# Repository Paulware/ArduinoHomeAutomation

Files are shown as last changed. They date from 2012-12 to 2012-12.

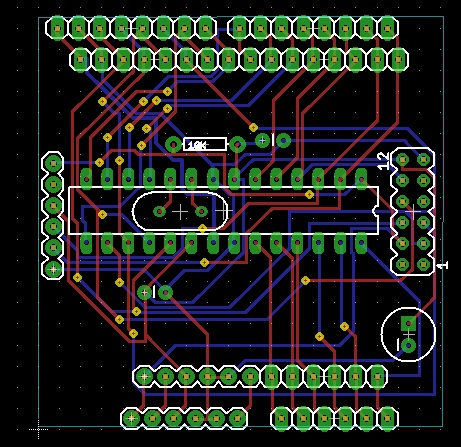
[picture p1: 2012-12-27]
schematics/EtherWeeny2/EtherWeeny2.jpg

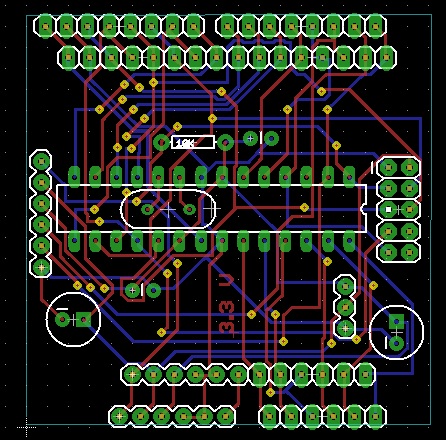
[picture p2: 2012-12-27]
schematics/EtherWeeny/EtherWeeny.jpg

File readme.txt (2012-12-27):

View the HomeAutomation.docx file for detailed information on setup.

Arduino sketches are located in the sketches directory
  The server directory has a the webserver sketch.
  The deviceClient has an example client sketch

Eagle schematics are located for enc28J60 DIY Arduino PCBs.
In the schematics directory
   1) EtherWeeny is a standard pcb for standard 10 pin ENC28J60.  A 3.3 V voltage regulator is added.
   2) EtherWeeny2 is a pcb for the less standard 12 pin ENC28J60.  This device has its own 3.3V regulator built in.

Web-Pages that can be run on an ipad or laptop are located in the webPages directory.
   1) tank.htm is an example that can be used to drive a tank.  A specific matching client sketch is not yet
      available for this tank.htm   
   
Future schematics and sketches will be added for X-10 control.

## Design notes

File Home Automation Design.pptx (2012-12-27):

## Home Automation Design

http://fiverr.com/paulware/help-with-your-arduino-project

## Overview

Ipad/laptop/notebook control

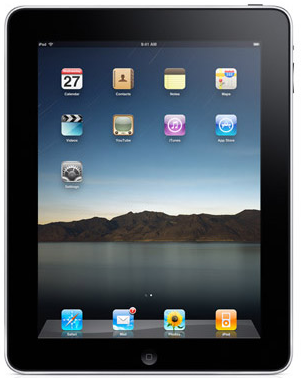
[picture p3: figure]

ENC28J60 web-server connected to wireless router

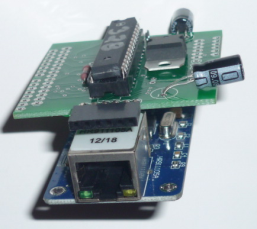
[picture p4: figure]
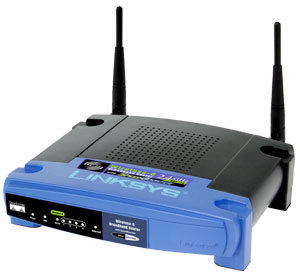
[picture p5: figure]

ENC28J60 web-client connected to TP-LINK 702n router repeater

Mobile Device

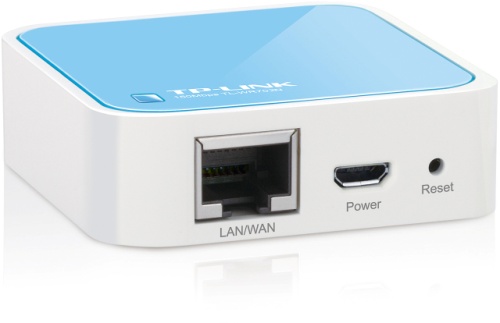
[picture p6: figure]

## Printed Circuit Board

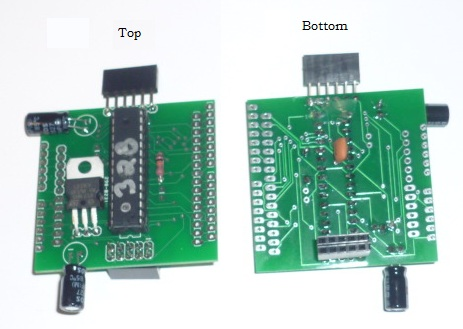
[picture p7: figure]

## CP2102 Usb to Serial Converter

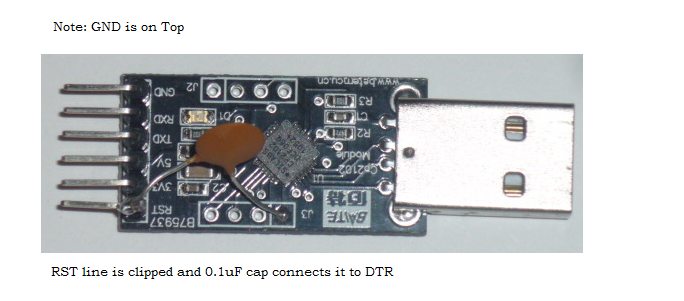
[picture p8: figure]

## Ready for Programming

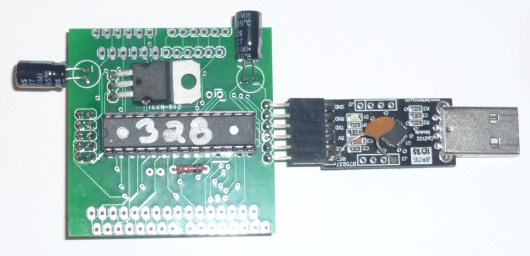
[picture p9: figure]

Select 328 in Arduino IDE Tools, Board

## 5 volt usb power supply

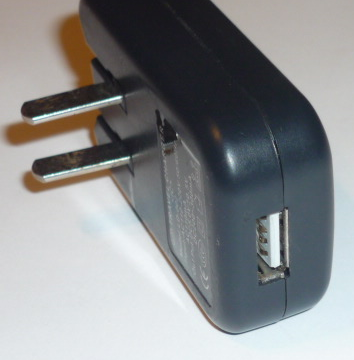
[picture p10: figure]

Available from ebay for $3.00

## Connect to power supply

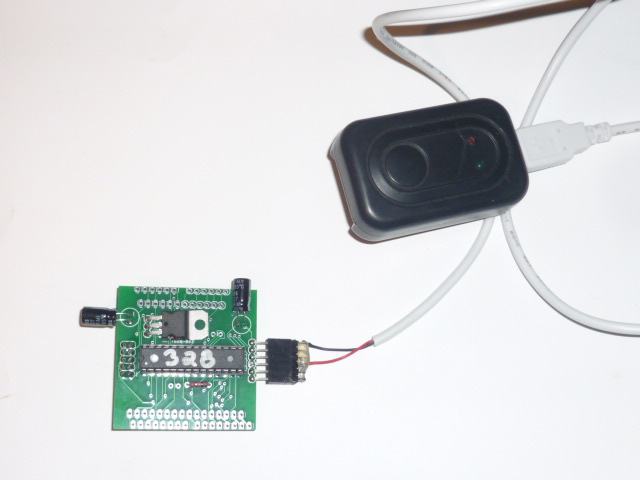
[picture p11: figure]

Note
GND

## ENC28J60

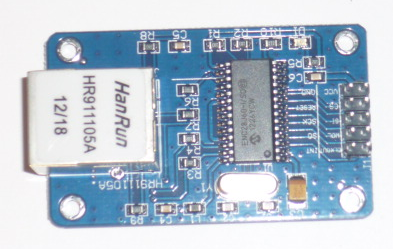
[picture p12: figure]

Available on ebay for less than $5.00 with free shipping

## Connected to ENC28J60

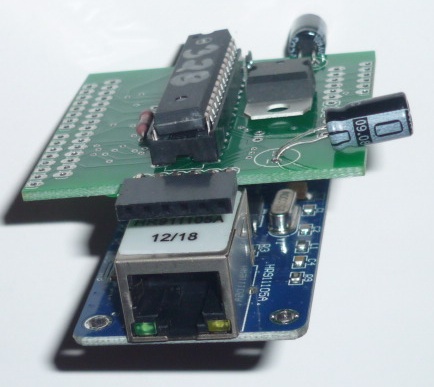
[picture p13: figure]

Web-server and web-clients appear identical

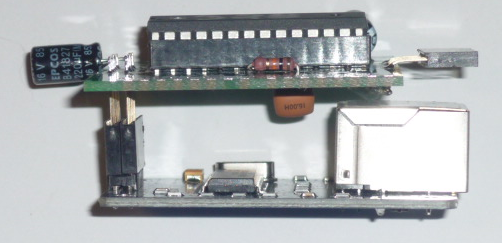
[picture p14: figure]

## Pinout of pcb

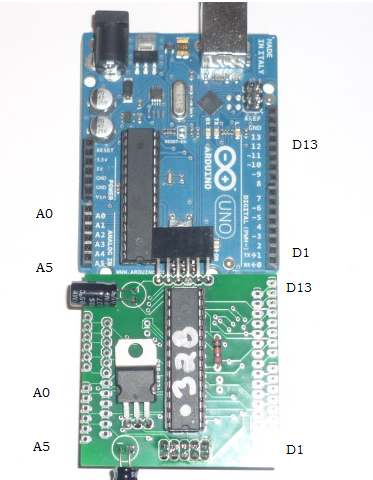
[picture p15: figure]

Same as an Arduino

## Router setup

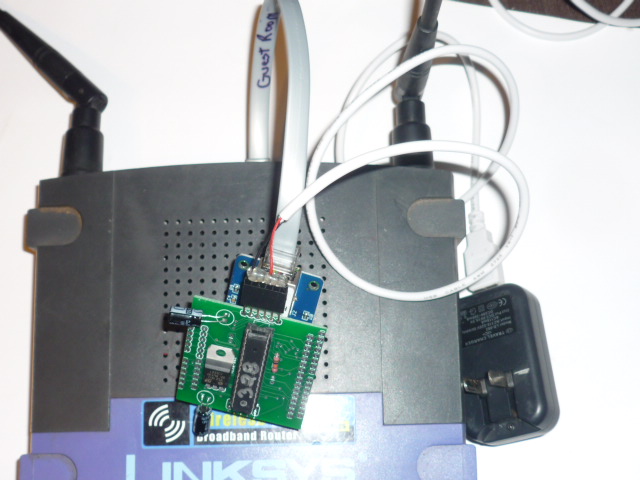
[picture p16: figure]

Web-server is connected here. Sketch should be modified to reflect router address

## X10 Control

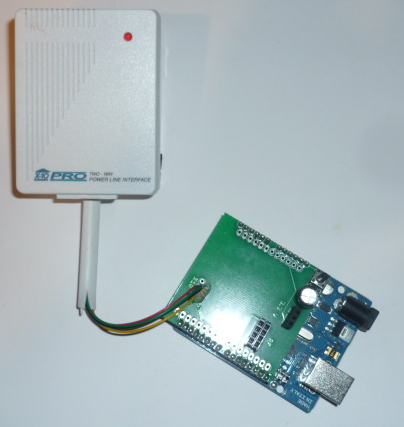
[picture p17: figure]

Arduino can turn X10 devices on or off.

## Mobile Device

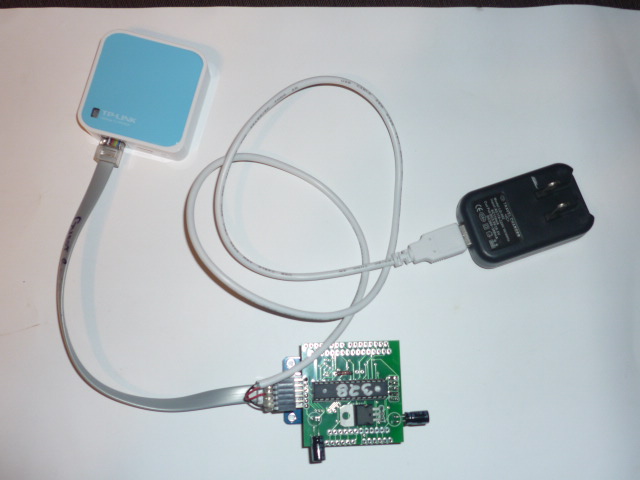
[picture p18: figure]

TP-Link 702n Router Repeater
Give Wifi capability to moble device controlled by Arduino-PCB

## Will move client/server code to github if requested http://fiverr.com/paulware/help-with-your-arduino-project

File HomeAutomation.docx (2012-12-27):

Arduino Home Automation featuring TP-Link 702n and ENC28J60

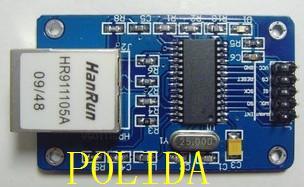
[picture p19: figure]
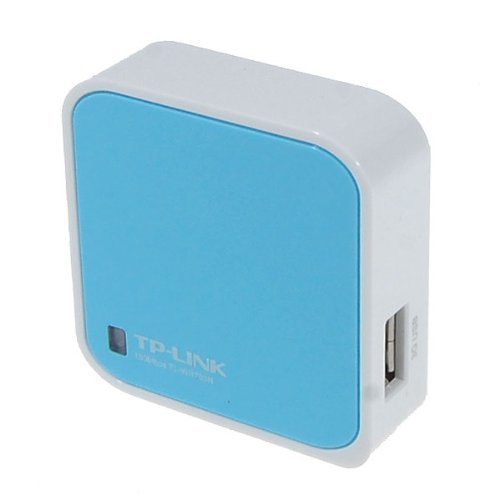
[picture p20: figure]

By Paul Richards and Manuel Tijerino

Overview:

An Ipad can be used to control irrigation systems, lights, house temperature, and even water plants. It can also be used to read temperature sensors, humidity sensors even sump pumps. Inexpensive wireless sensor and control nodes can be created using a TP-Link 702n ($22) and an ENC28J60 ($5.00) and DIY Arduino pcbs ($7.00). X-10 (with a DIY arduino control) can also be used to controlled power to lights.

The system is started with an existing wireless router. TP-Link modules are placed in repeater mode so that ENC28J60 (connected to DIY arduinos) can communicate with the system wirelessly.

Here are the required steps:

1. Place a TP-Link 702n in repeater mode
2. Create a DIY Arduino Web-Server that can be written to ($7.00). Connect it directly to your wireless router
3. Create a DIY Arduino Web-Client and connect it to the TP-Link 702n
4. Command the Web-Client using an Ipad or notebook computer  This project is located on github: https://github.com/Pualware/ArduinoHomeAutomation

Configure a TP-Link in Repeater Mode

1. Set your PC Lan IP4 properties so that it is on the same subnet as the TP-Link 702n (note: the default IP address of a TP-Link 702n is 192.168.0.254)

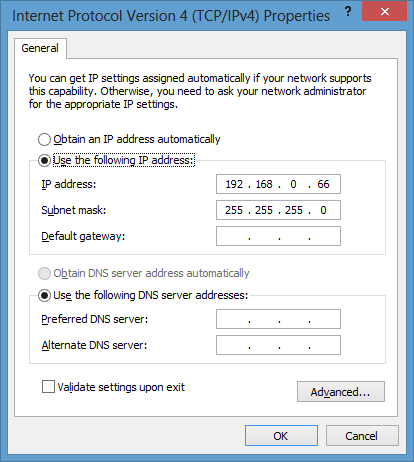
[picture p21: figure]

2. Acces TP-Link 702n located at http://192.168.0.254 from laptop via ethernet cable (note: username is admin, and password is admin). Select Repeater and press the Next button

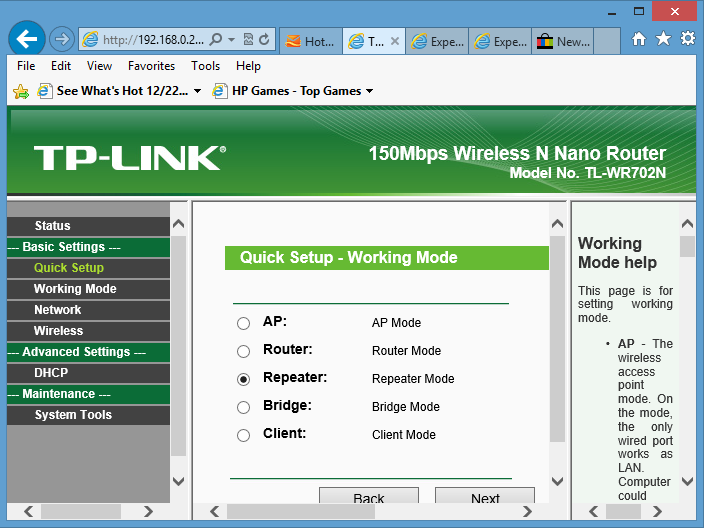
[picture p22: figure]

3. Select Survey and select your network, then select the same Security Options as your network and enter the correct password. Then press Next.

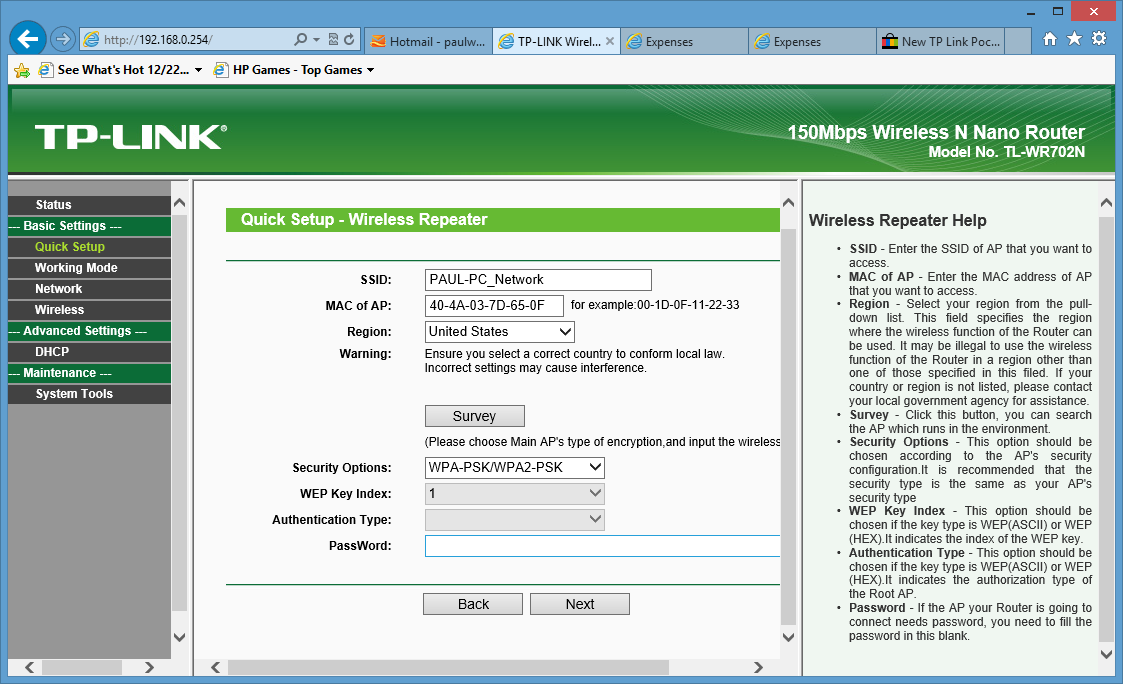
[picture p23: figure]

4. The default setting for DHCP in Repeater mode is disabled. You will need DHCP enabled for your client nodes so enable DHCP in DHCP Settings:

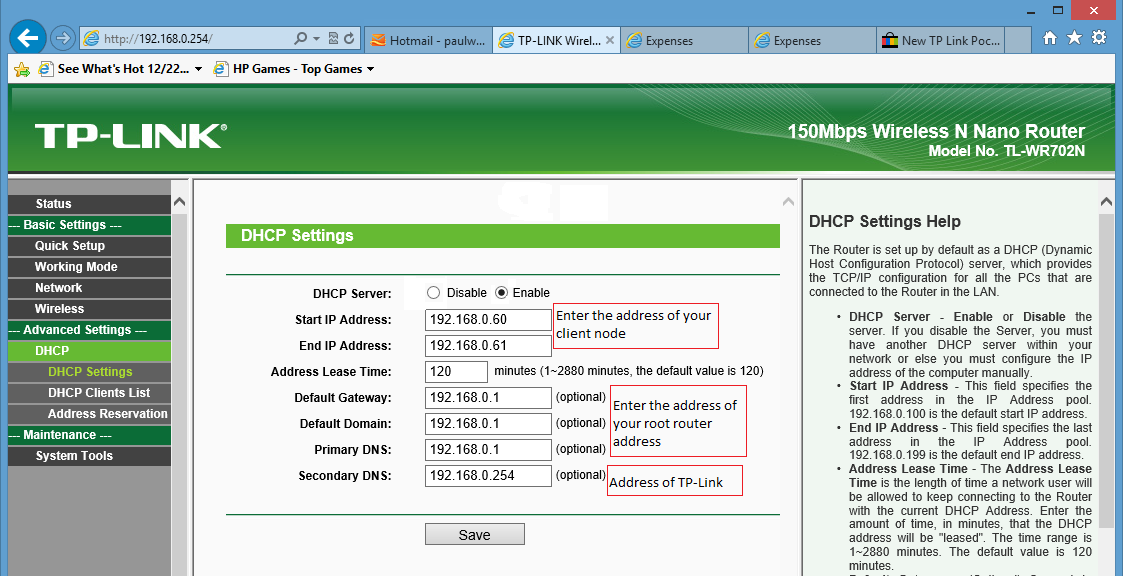
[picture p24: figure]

Your tp-link is now setup. To verify that it works. Turn off your wireless laptop connection and connect an Ethernet cable directly from your laptop to the 702n. You should be able to get to the internet via the tp-link. Change your pc lan properties for TCP/IPV4 to optain IP Address automatically. The Tp-Link will assign the pc the address 192.168.0.60.

You can verify that the pc has the correct ip address by running ipconfig. In windows 8 press the windows key and the “r” this will bring up the Run dialog box. Enter “cmd” and then change directory to c:\windows\system32 from there you run ipconfig and should see:

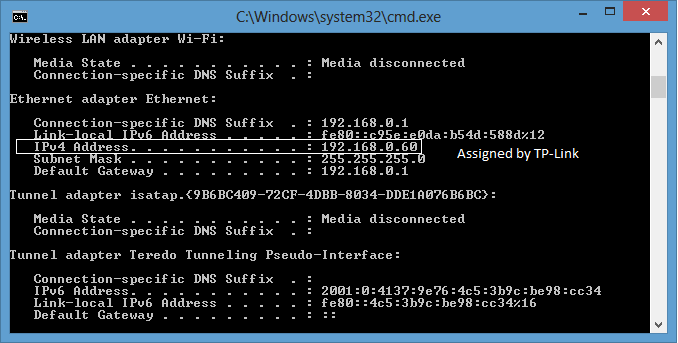
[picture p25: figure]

The system is now ready for the TP-Link 702n to be directly connected to the DIYArduino Client


Connect the 2102 usb to serial adapter to the DIYArduino Client and flash the unit using the Arduino IDE. Use the client sketch found at Github to flash the unit.

From the Arduino IDE, start the serial monitor. Assuming your DIY Arduino webServer is connected and you have already entered the command: http://192.168.0.50/discoverKingTiger1. You should see a display like this in the Serial Monitor:

[webClient]

access Ethernet controller ok

IP: 192.168.0.61

GW: 192.168.0.1

DNS: 192.168.0.1

SRV: 192.168.0.50

0:0:0:0:0:0:100:0:0:100:0:0:0:0:0:0:0:0:0:0

This means that the client has been assigned the address of 192.168.0.61 by the 702n. The gateway is established to the root modem/router. The DNS name server is established to the root modem/router and the DIY web-server located at 192.168.0.50 is visible to the client device. Further, all the port values were read from the web-server for this device named “KingTiger1”

Commands recognized by the DIY Arduino Web-Server are:

1. discover This command lets the web server know that a device exists on the network. It must be followed by a unique device name for example: discoverKingTiger1 For example this lets the web server know that a device by the name of KingTiger1 exists.
2. show This command lists all the devices currently connected. Here is an example output:

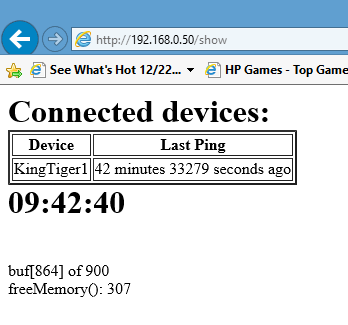
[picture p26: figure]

3. write This command is used to write to ports on the specified device. For example: writeKingTiger1:19:1:5:100:3:200 writes the value 1 to port 19, the value 100 to port 5 and the value 200 to port 3
4. read This command is used to read all the ports on the specified device. For example: readKingTiger1 Tells the web-server to echo the value for all ports on the device KingTiger1.

Sketches for the web server and web-client, as well as the schematics to build the DIY Arduino components will be located on Github:

https://github.com/Pualware/ArduinoHomeAutomation

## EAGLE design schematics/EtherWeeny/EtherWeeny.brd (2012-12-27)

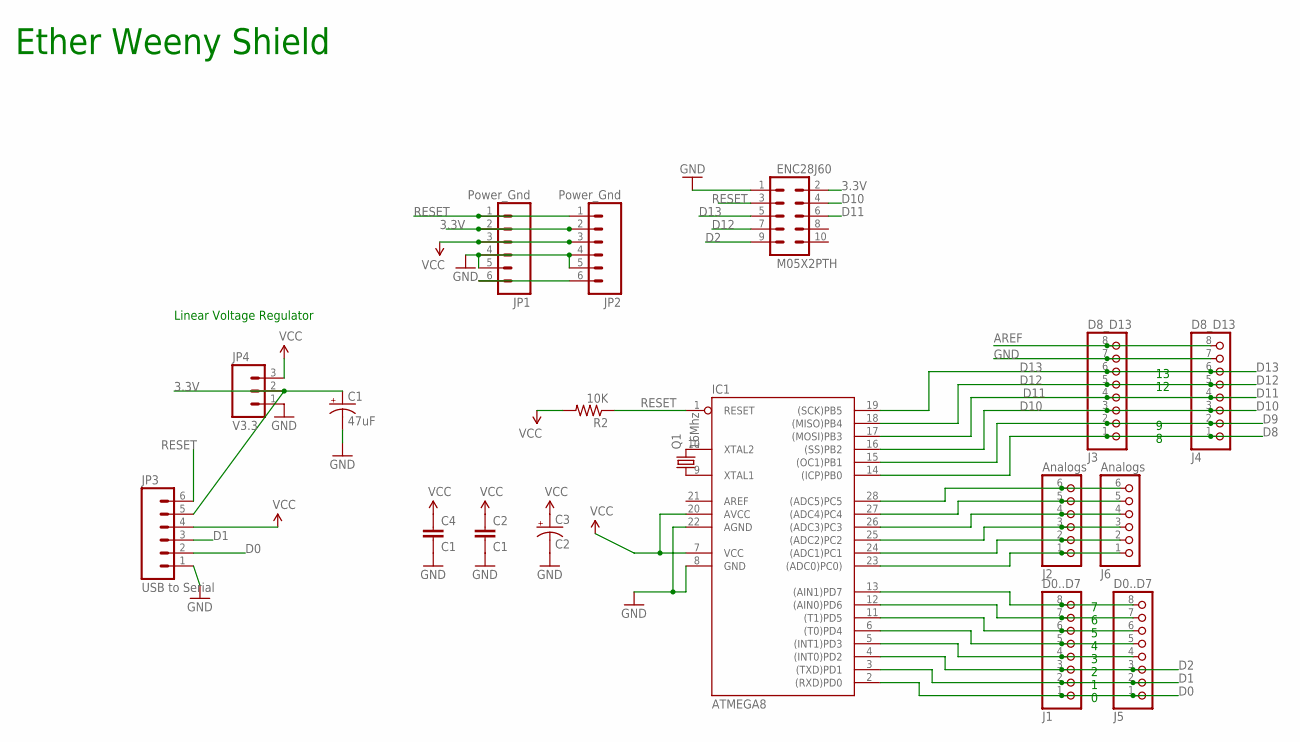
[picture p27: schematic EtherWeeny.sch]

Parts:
C1: 47uF; CPOL-RADIAL-100UF-25V
C2, C4: C1; CAP-PTH-SMALL
C3: C2; CPOL-RADIAL-100UF-25V
ENC28J60: M05X2PTH; AVR_ICSP
IC1: ATMEGA8; DIL28-3
J1, J5: D0..D7; 1X08
J2, J6: Analogs; 1X06
J3, J4: D8_D13; 1X08
JP1, JP2: Power_Gnd; 1X06
JP3: USB to Serial; 1X06
JP4: V3.3; 1X03
Q1: 16Mhz; HC49US
R2: 10K; AXIAL-0.3

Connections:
3.3V: C1.1 (+), ENC28J60.2, JP1.2, JP2.2, JP3.5, JP4.2
AREF: IC1.21 (AREF), J3.8, J4.8
D0: IC1.2 ((RXD)PD0), J1.1, J5.1, JP3.2
D1: IC1.3 ((TXD)PD1), J1.2, J5.2, JP3.3
D2: ENC28J60.9, IC1.4 ((INT0)PD2), J1.3, J5.3
D8: IC1.14 ((ICP)PB0), J3.1, J4.1
D9: IC1.15 ((OC1)PB1), J3.2, J4.2
D10: ENC28J60.4, IC1.16 ((SS)PB2), J3.3, J4.3
D11: ENC28J60.6, IC1.17 ((MOSI)PB3), J3.4, J4.4
D12: ENC28J60.7, IC1.18 ((MISO)PB4), J3.5, J4.5
D13: ENC28J60.5, IC1.19 ((SCK)PB5), J3.6, J4.6
GND: C1.2 (-), C2.2, C3.2 (-), C4.2, ENC28J60.1, IC1.8 (GND), IC1.22 (AGND), J3.7, J4.7, JP1.4, JP1.5, JP2.4, JP2.5, JP3.1, JP4.1
unnamed: IC1.10 (XTAL2), Q1.2
unnamed: IC1.9 (XTAL1), Q1.1
unnamed: JP1.6, JP2.6
unnamed: IC1.5 ((INT1)PD3), J1.4, J5.4
unnamed: IC1.6 ((T0)PD4), J1.5, J5.5
unnamed: IC1.11 ((T1)PD5), J1.6, J5.6
unnamed: IC1.12 ((AIN0)PD6), J1.7, J5.7
unnamed: IC1.13 ((AIN1)PD7), J1.8, J5.8
unnamed: IC1.23 ((ADC0)PC0)), J2.1, J6.1
unnamed: IC1.24 ((ADC1)PC1), J2.2, J6.2
unnamed: IC1.25 ((ADC2)PC2), J2.3, J6.3
unnamed: IC1.26 ((ADC3)PC3), J2.4, J6.4
unnamed: IC1.27 ((ADC4)PC4), J2.5, J6.5
unnamed: IC1.28 ((ADC5)PC5), J2.6, J6.6
RESET: ENC28J60.3, IC1.1 (RESET), JP1.1, JP2.1, JP3.6, R2.P$1 (1)
VCC: C2.1, C3.1 (+), C4.1, IC1.7 (VCC), IC1.20 (AVCC), JP1.3, JP2.3, JP3.4, JP4.3, R2.P$2 (2)

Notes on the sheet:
Ether Weeny Shield
Linear Voltage Regulator

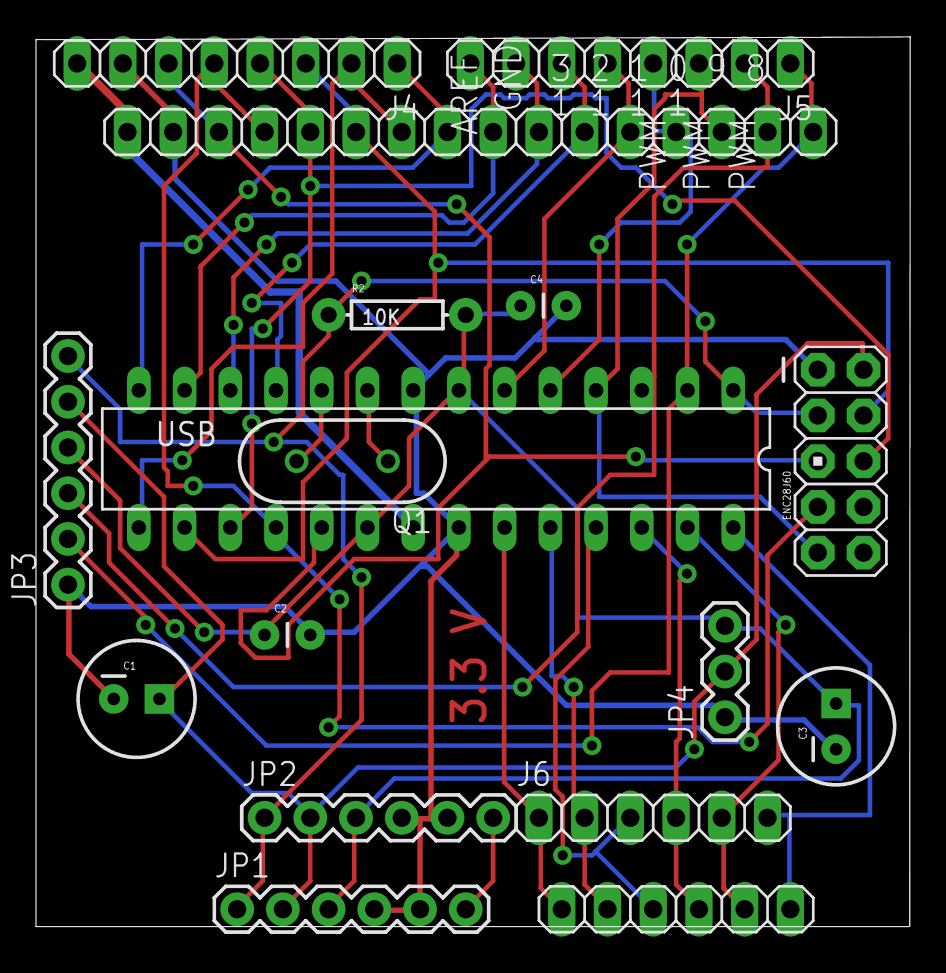
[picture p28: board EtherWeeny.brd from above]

Board: 2 copper layers, 48.6 x 49.4 mm, 18 parts (0 on the bottom side), 28 nets.

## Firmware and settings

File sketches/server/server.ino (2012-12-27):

#include <EtherCard.h>
#include <MemoryFree.h>
#include <EEPROM.h>
#include "ProgmemStrings.h"
#include "EEPROMStructs.h"
#define SERVERIP "192.168.0.50"

static int const MAXBUFFER = 900;

// ethernet interface mac address, must be unique on the LAN
static byte mymac[] = { 
  0x74,0x69,0x69,0x2D,0x30,0x31 };
static byte myip[4];
byte Ethernet::buffer[MAXBUFFER];
BufferFiller bfill;
int numDevices = 0;
ProgmemStrings progStrings(6);
EEPROMStructs structures = EEPROMStructs();

struct DeviceType
{
  unsigned long lastPing;  // last millis() that device sent a ping
  char * name;             // Unique text name of device
};
DeviceType devices[25];

void SetupByteArray (byte * myip )
{
  int len = strlen (SERVERIP);
  int count = 0;
  char serverIp[] = SERVERIP;
  char addr[4];
  int index = 0;

  for (int i=0; i<len; i++)
  {
    if (serverIp[i] == '.')
    {
      addr[count] = 0;
      myip[index++] = (byte) atoi (addr);
      count = 0;
    }  
    else
      addr[count++] = serverIp[i];      
  }

  addr[count] = 0;
  myip[index++] = (byte) atoi (addr);

  ProgmemStrings::printPSTR ( PSTR ( "myip:" ));
  for (int i=0; i<4; i++)
  {
    if (i==0)
      Serial.print ( "{");
    else  
      Serial.print ( ",");
    Serial.print ( myip [i]);    
  }
  Serial.println ("}");     
}

void setup () {
  int which;
  Serial.begin (115200);
  ProgmemStrings::printPSTR ( PSTR ( "rbbb_server_progstrings" ) ); 
  SetupByteArray (myip);
  if (ether.begin(sizeof Ethernet::buffer, mymac) == 0)
    ProgmemStrings::printPSTR ( PSTR ( "Failed to access Ethernet controller"));
  ether.staticSetup(myip);
  
  progStrings.addString ( PSTR ( "discover" ));
  progStrings.addString ( PSTR ( "show" ));
  progStrings.addString ( PSTR ( "page" ));
  progStrings.addString ( PSTR ( "ping" ));
  progStrings.addString ( PSTR ( "write" ));
  progStrings.addString ( PSTR ( "read" ));
  progStrings.showAll();
  ProgmemStrings::printPSTR ( PSTR ( "Free Memory: " ) );
  Serial.println ( freeMemory() );  
}

// str1 is the actual string
bool strEqual ( char * str1, char * str2 )
{
  bool match = true;
  int len = strlen ( str1 );

  if (strlen(str2) < len) 
    match = false;
  else 
    for (int i=0; i<len; i++)
    {
      if (str1[i] != str2[i])
      {
        match = false;
        break;
      }
    }

  return match;
}

int findDevice (char * name)
{
  int found = -1;
  for (int i=0; i<numDevices; i++)
  {
    if (strEqual (devices[i].name, name) )
    {
      found = i;
      break;
    }  
  }  
  return found;
}

char * findParameterStart ()
{
  char ch;
  int index = 0;
  int ind = 0;
  int state = 0;
  byte * startParam;

  while (state != 2)
  {
    ch = ether.buffer[index++];
    if (ch == ' ') 
      state = 1;
    else if ((state == 1) && (ch == '/'))
      state = 2;
    else 
      state = 0;
  }  
  startParam = &ether.buffer[index];
  return (char *)startParam;
}


void findCommand ( char * &line, int & cmd )
{
  int len;
  cmd = progStrings.findString ( line );
  if (cmd > -1)
  {
    len = progStrings.stringLen (cmd );
    line = line + len;
  }
}

char * copyParam ( char * parameter )
{
  int len = 0;
  int offset = 0;
  char ch;
  char * param;
  int state = 0;
  // find out how long is the parameter 
  while (true)
  {
    ch = parameter[len];
    if (ch == ' ') 
      break;
    else 
    {
      Serial.print ( ch ); 
      Serial.print ( " = " );
      Serial.println ( (int) ch );
    }  
    switch (state)
    {
      case 0:
        if (ch == '%')
          state = 1;
      break;
      case 1:
        if (ch == '2')
          state = 2;
        else
          state = 0;
      break;
      case 2:
        if (ch == '0')
          offset -= 2;          
        state = 0;
      break;
    } 
    len++;
  }
  param = (char *) calloc (len+1+offset,1); // allocate the string
  len = 0;
  offset = 0;
  // Copy the parameter
  while (true)
  {
    ch = parameter [len];
    if (ch == ' ')
      break;
    if ((parameter[len] == '%') && (parameter[len+1]=='2') && (parameter[len+2]=='0'))
    {
      ch= ' ';
      len = len + 2;
      offset = offset - 2;
    }  
    param[len+offset] = ch;
    len++;
  }
  ProgmemStrings::printPSTR ( PSTR ( "param: " ));
  Serial.print ( param );
  Serial.println ( "." );
  
  return param;  
}

void loop () {
  word len = ether.packetReceive();
  char * parameter;
  word pos = ether.packetLoop(len);
  char ch;
  bool debugIt = false;
  int pageNumber = -1;
  int command; 
  char * paramCopy;

  if (pos)  // check if valid tcp data is received
  {
    parameter = findParameterStart ();
    findCommand (parameter, command);
    paramCopy = copyParam ( parameter );
    ProgmemStrings::printPSTR ( PSTR ( "paramCopy len:" ));
    Serial.print ( strlen ( paramCopy ) );
    Serial.print ( ":" );
    Serial.println ( paramCopy );
    ProgmemStrings::printPSTR ( PSTR ( "paramCopy: " )); 
    Serial.println ( (int) paramCopy );
    
    ether.httpServerReply(serverPage (command, paramCopy)); // send web page data
    delete (paramCopy);
  }
}

// Do not consume the terminating 0
boolean readDecimal (char * &charPointer, int &total)
{
  char ch;
  boolean ok = false;
  total = 0;
  
  while (true)
  {
    ch = *charPointer;
    // Exit if number if not a decimal
    if ((ch < '0') || (ch > '9'))
      break;
    else
    {
      ok = true;
      charPointer++;
      total *= 10;
      total += ch - '0';
    }    
  }    
  return ok;
}

void handleShow ()
{
  long t = millis() / 1000;
  word h = t / 3600;
  byte m = (t / 60) % 60;
  byte s = t % 60;
  float secondsAgo;
  
  bfill.emit_p(PSTR(
    "HTTP/1.0 200 OK\r\n"
    "Content-Type: text/html\r\n"
    "Pragma: no-cache\r\n"
    "\r\n"
    "<title>Show Devices</title>" 
    "<h1>Connected devices:<br>"
    "<table border=\"2px solid\">"
    "<tr><th>Device</th><th>Last Ping</th></tr>"));

  for (int i=0; i<numDevices; i++)
  {
    Serial.print ( i );
    Serial.print ( "):" );
    Serial.println ( devices[i].name );
    secondsAgo = millis() - devices[i].lastPing;
    secondsAgo /= 1000.0; 
    m = secondsAgo / 60.0;
    if (m > 0) 
      bfill.emit_p (PSTR ( "<tr><td>$S</td><td>$D minutes $D seconds ago</td></tr>"),devices[i].name, m, (int) secondsAgo);
    else  
      bfill.emit_p (PSTR ( "<tr><td>$S</td><td>$D seconds ago</td></tr>"),devices[i].name, (int) secondsAgo);
  }  
  bfill.emit_p (PSTR (
    "</table>"
    " $D$D:$D$D:$D$D</h1><br>buf[$D] of $D<br>"),
    h/10, h%10, m/10, m%10, s/10, s%10, (int) bfill.ptr, MAXBUFFER);
    
  bfill.emit_p (PSTR ( " freeMemory(): $D<br>"), freeMemory());
}

void handleWrite (char * parameter)
{
  int len;
  int device;
  int port;
  int value;

  device = findDevice (parameter); 
  len = strlen (devices[device].name);    
  if (device > -1) 
  {
    parameter += len;
      
    while (readDecimal (++parameter, port ) && readDecimal (++parameter, value))
      structures.updateValue ( device, port, value );
      
    bfill.emit_p(PSTR(
      "HTTP/1.0 200 OK\r\n"
      "Content-Type: text/html\r\n"
      "Pragma: no-cache\r\n"
      "\r\n"
      "<title>ping RBBB server page </title>"
      "<h1>write detected $S device found<br>"), parameter);
  }
  else
  {
    bfill.emit_p(PSTR(
      "HTTP/1.0 200 OK\r\n"
      "Content-Type: text/html\r\n"
      "Pragma: no-cache\r\n"
      "\r\n"
      "<title>ping RBBB server page </title>"
      "<h1>$S<br>"), "Write detected, device not found");
  }
}

void handleRead ( char * parameter )
{
  int len;
  int device;
  int port;
  int value;
  
  device = findDevice (parameter); 
  if (device > -1) 
  {
    len = strlen (devices[device].name);   
    parameter += len;
    ProgmemStrings::printPSTR ( PSTR ( "parameter in read: " ));
    Serial.println ( parameter );
    value = -1; 
    if (readDecimal (++parameter, port ))
    {
      value = structures.readValue ( device, port );
      bfill.emit_p(PSTR(
        "HTTP/1.0 200 OK\r\n"
        "Content-Type: text/html\r\n"
        "Pragma: no-cache\r\n"
        "\r\n"
        "<h1>read detected for $S port: $D value: $D<br>"), 
         devices[device].name, port, value);
    }  
    else
    {
      ProgmemStrings::printPSTR ( PSTR ( "No port provided, read all values" ));  
      bfill.emit_p(PSTR(
        "HTTP/1.0 200 OK\r\n"
        "Content-Type: text/html\r\n"
        "Pragma: no-cache\r\n"
        "\r\n"));
      
      for (int i=0; i<MAXARDUINOPORTS; i++)
      {
        value = structures.readValue ( device, i);
        if (!i)
          bfill.emit_p (PSTR ( 
          "$D"),
          value );
        else
          bfill.emit_p (PSTR ( 
          ":$D"),
          value );
        
      }
    }               
  }
  else
    bfill.emit_p(PSTR(
      "HTTP/1.0 200 OK\r\n"
      "Content-Type: text/html\r\n"
      "Pragma: no-cache\r\n"
      "\r\n"
      "<title>ping RBBB server page </title>"
      "<h1>$S<br>"), "read detected, device not found");
}

static word serverPage(int command, char * parameter) {
  int len;
  int device;
  char discovered[3] = "";
  int port;
  int value;
    
  bfill = ether.tcpOffset();
  
  ProgmemStrings::printPSTR ( PSTR (  "Command: " ) ) ;
  progStrings.show ( command, command+1 );

  switch ( command )
  {
  case 0: // discover
    len = strlen (parameter); 
    ProgmemStrings::printPSTR ( PSTR (  "Device detected:") );
    Serial.print (parameter);
    Serial.println();
    device = findDevice (parameter); 
    if (device > -1)
      devices[device].lastPing = millis();
    else
    { 
      devices[numDevices].lastPing = millis();
      devices[numDevices].name = (char *) calloc (len+1,1);
      strcpy (devices[numDevices].name, parameter);
      structures.clearDevice (numDevices++);
    }  

    if (device > -1)
      strcpy ( discovered, "re");
    
    bfill.emit_p(PSTR(
    "HTTP/1.0 200 OK\r\n"
      "Content-Type: text/html\r\n"
      "Pragma: no-cache\r\n"
      "\r\n"
      "<title border=\"2px solid\">Device Discovery</title>" 
      "<h1>A device was $S discovered: $S</h1><br>"),
    discovered, parameter); 
    break;

  case 1: // show
    handleShow();
    break;
  
  case 2: // page
    bfill.emit_p(PSTR(
    "HTTP/1.0 200 OK\r\n"
      "Content-Type: text/html\r\n"
      "Pragma: no-cache\r\n"
      "\r\n"
      //"<meta http-equiv='refresh' content='1'/>"
    "<title>RBBB server page </title>"
      "<h1>$S<br>"), parameter);
    break;
    
  case 3: // ping
    device = findDevice (parameter); 
    if (device > -1) 
    {
      bfill.emit_p(PSTR(
        "HTTP/1.0 200 OK\r\n"
        "Content-Type: text/html\r\n"
        "Pragma: no-cache\r\n"
        "\r\n"
        "<title>ping RBBB server page </title>"
        "<h1>$S<br>"), "Ping detected, device found");
      devices[device].lastPing = millis();
    }        
    else
      bfill.emit_p(PSTR(
        "HTTP/1.0 200 OK\r\n"
        "Content-Type: text/html\r\n"
        "Pragma: no-cache\r\n"
        "\r\n"
        "<title>ping RBBB server page </title>"
        "<h1>$S<br>"), "Ping detected, device not found");
    
    break;  

  case 4: // write to a port on the device
    handleWrite (parameter);
    break;
    
  case 5: // read from a port on the device
    handleRead ( parameter );
    break;

  default: // atoi will return 0 if no page detected
    bfill.emit_p (PSTR ( 
    "HTTP/1.0 200 OK\r\n"
      "Content-Type: text/html\r\n"
      "Pragma: no-cache\r\n"
      "\r\n"
      "<html><head>\r\n"
      "<title>Unknown page $D</title>"
      "<body>"
      "Oops Unknown page: $D requested sorry\r\n"
      "</body></html>"), parameter);
    break;
  }  

  return bfill.position();
}

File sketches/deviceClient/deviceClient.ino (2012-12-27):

#include <EtherCard.h>

// ethernet interface mac address, must be unique on the LAN
static byte mymac[] = { 0x74,0x69,0x69,0x2E,0x30,0x31 };
// static byte myip[4];
static byte myip[] = { 192,168,0,188 };
// gateway ip address
static byte gwip[] = { 192,168,0,1 };

byte Ethernet::buffer[700];
unsigned long timeout = 0;

#define MYIP "192.168.0.60"
// Location of web-server
char website[] PROGMEM = "192.168.0.50";

char * findString ( char * source, char * target ) 
{
  char * found = 0;
  int len = strlen ( source );
  char ch;
  char ch1;
  char count=0;
  
  for (int i=0; i<len; i++)
  {
    ch = source[i];
    ch1 = target[count];
    found = &source[i];
    if (ch == ch1)
    {
      count++;
      if (count == strlen(target)) // match
        break;
    }
    else
      count = 0;

  }
  if (count != strlen ( target )) // no match
    found = 0;
    
  return found;
}

// Do not consume the terminating 0
boolean readDecimal (char * &charPointer, int &total)
{
  char ch;
  boolean ok = false;
  total = 0;
  
  while (true)
  {
    ch = *charPointer;
    // Exit if number if not a decimal
    if ((ch < '0') || (ch > '9'))
      break;
    else
    {
      ok = true;
      charPointer++;
      total *= 10;
      total += ch - '0';
    }    
  }    
  return ok;
}

// called when the client request is complete
static void my_callback (byte status, word off, word len) 
{
  char ch = ' ';
  int count = 0;  
  int i = 0;
  int state = 0;
  
  while (state != 4) 
  {
    ch = Ethernet::buffer[i++];    
    switch (state)
    {
      case 0:
        if (ch == 13)
          state = 1;
        else
          state = 0;
      break;
      case 1:
        if (ch == 10)
          state = 2;
        else
          state = 0;
      break;
      case 2:
        if (ch == 13)
          state = 3;
        else
          state = 0;
      break;
      case 3:
        if (ch == 10)
          state = 4;
        else
          state = 0;
      break;
    }
  }
  
  Ethernet::buffer[off+300] = 0;
  while (ch)
  {
    ch = Ethernet::buffer[i++];
    Serial.print ( ch );
  }
  Serial.println ();
  //Serial.print((const char*) Ethernet::buffer + off+30);
  //Serial.println("...");
  /*
  char * found;
  int which;
  char ch;
  static int last[20] = {0,0,0,0,0,0,0,0,0,0,0,0,0,0,0,0,0,0,0};
  static int d;
  int offset = 0;
  
  // Serial.print ( "." );
  
  Ethernet::buffer[off+300] = 0;
  Serial.print ( "off: " );
  Serial.print ( off );
  Serial.print ( "len: " );
  Serial.println ( len );
  Serial.println ( Ethernet::buffer[off+62] );
  
  /*
    NOTE: Server puts out a page that has this data embedded:
    parent.sId "dX","checked","false"
    
    Where X is the number of the discrete that is being read
  */  

  //for (int i=0; i<20; i++)
  //{
     /* 
       Note: 62 is to skip the 
       "HTTP/1.0 200 OK\r\nContent-Type: text/html\r\nPragma: no-cache\r\n\r\n"
       which is output be the server on each response
     */
     //ch = Ethernet::buffer[off+62+offset];    
     /* 
     offset++;
     d = 0;
     while ((ch <= '9') && (ch >= '0'))
     {
       d *= 10;
       d += ch - '0';
       ch = Ethernet::buffer[off+62+offset];
       offset++;
     }
     */
     // Serial.print ( Ethernet::buffer[off+62+offset]);
     /*
     if (d != last[i])
     {
       Serial.print ("D");
       Serial.print (i);
       Serial.print ("=");
       Serial.println ( d );
       last[i] = d;
     }  
     */
  //}
  
}
/*
void SetupByteArray (byte * myip )
{
  int len = strlen (MYIP);
  int count = 0;
  char ipAddress[] = MYIP;
  char addr[4];
  int index = 0;

  for (int i=0; i<len; i++)
  {
    if (ipAddress[i] == '.')
    {
      addr[count] = 0;
      myip[index++] = (byte) atoi (addr);
      count = 0;
    }  
    else
      addr[count++] = ipAddress[i];      
  }

  addr[count] = 0;
  myip[index++] = (byte) atoi (addr);

  Serial.print ( "myip:" );
  for (int i=0; i<4; i++)
  {
    if (i==0)
      Serial.print ( "{");
    else  
      Serial.print ( ",");
    Serial.print ( myip [i]);    
  }
  Serial.println ("}");     
}
*/

void setup () {
  Serial.begin(115200);  
  Serial.println("\n[webClient]");

  if (ether.begin(sizeof Ethernet::buffer, mymac) == 0) 
    Serial.println( "Failed to access Ethernet controller");
  else
    Serial.println("access Ethernet controller ok" );  
  if (!ether.dhcpSetup())
    Serial.println("DHCP failed");

  ether.printIp("IP:  ", ether.myip);
  ether.printIp("GW:  ", ether.gwip);  
  ether.printIp("DNS: ", ether.dnsip); 
  
  if (!ether.dnsLookup(website))
    Serial.println("DNS failed");
    
  ether.printIp("SRV: ", ether.hisip);

  timeout = millis() + 2000; 
}

void loop ()
{
  ether.packetLoop(ether.packetReceive());
  if (millis() > timeout)
  {
      ether.browseUrl(PSTR("/"), "readKingTiger1", website , my_callback);      
      timeout = millis() + 2000; // 1 time a second
  }
}

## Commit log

2012-12-27 Initial Creation v.0.01 Prerelease
    Added documentation, sketches, schematics and web-pages
    [EtherWeeny.brd, EtherWeeny.sch, EtherWeeny2.brd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]
2012-12-27 V0.03
    Added power point documentation
